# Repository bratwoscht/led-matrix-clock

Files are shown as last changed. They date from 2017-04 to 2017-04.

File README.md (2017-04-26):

# led-matrix-clock
LED matrix clock with telegram bot

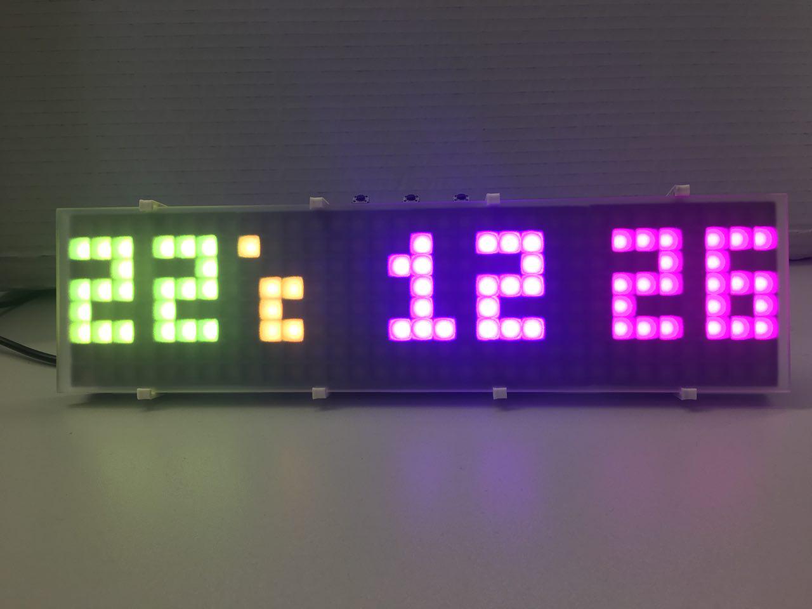
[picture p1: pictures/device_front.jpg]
device front

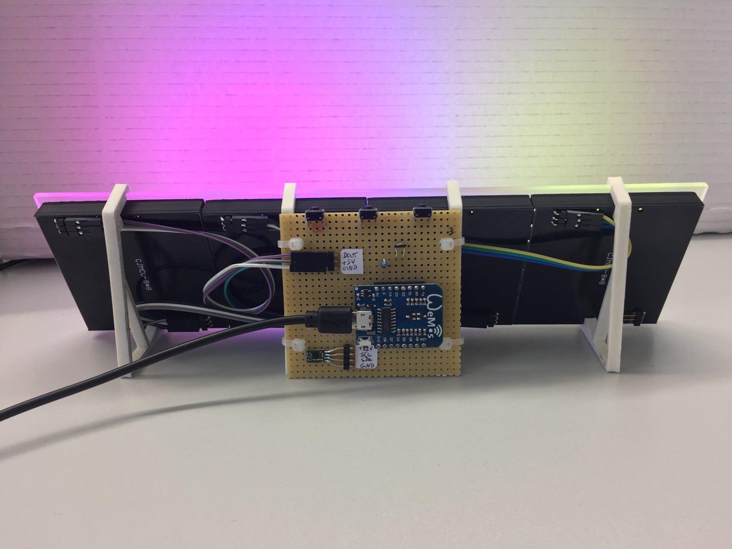
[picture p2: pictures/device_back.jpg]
device back


# Hardware

## Bill of materials

| Menge | Preis  | Beschreibung | Link |
| ----- | --- | --- | ----- |
| 1 | 0,22€  | 2.54mm THT Angled Pin Header| https://www.reichelt.de/index.html?ARTIKEL=SL%201X40W%202,54 |
| 4 | 10,66€ | 8x8 RGB LED Matrix with WS2812 LEDs (I soldered the angled pin headers). ATTENTION: On this module DIN and DOUT are interchanged. | https://www.banggood.com/de/CJMCU-64-Bit-WS2812-5050-RGB-LED-Driver-Development-Board-p-981678.html |
| 1 | 0,75€  | Prototyping board (approx. 70x70 mm) |  https://www.reichelt.de/index.html?ARTIKEL=HPR%20100X100 |
| 3 | 0,15€  | Push button. | https://www.reichelt.de/index.html?ARTIKEL=TASTER%203305 |
| 1 | 4,41€  | ESP8266 WLAN module | https://www.banggood.com/de/WeMos-D1-Mini-V2-NodeMcu-4M-Bytes-Lua-WIFI-Internet-Of-Things-Development-Board-Based-ESP8266-p-1115398.html |
| 1 | 1,15€  | LM75 I2C temperature sensor (I used a custom PCB from a former project) | http://www.ebay.de/itm/New-LM75A-Temperatur-Sensor-High-speed-I2C-Interface-Development-Board-Modul-/272434029114 |
| 1 | | LDR (unknown type with approx. 5-10kR at 10Lux) | | 
| 1 | 0,10€  | Resistor 1kR for the voltage divider at the LDR | https://www.reichelt.de/index.html?ARTICLE=1315 |

## Schematics

The prototyping pcb look like this:
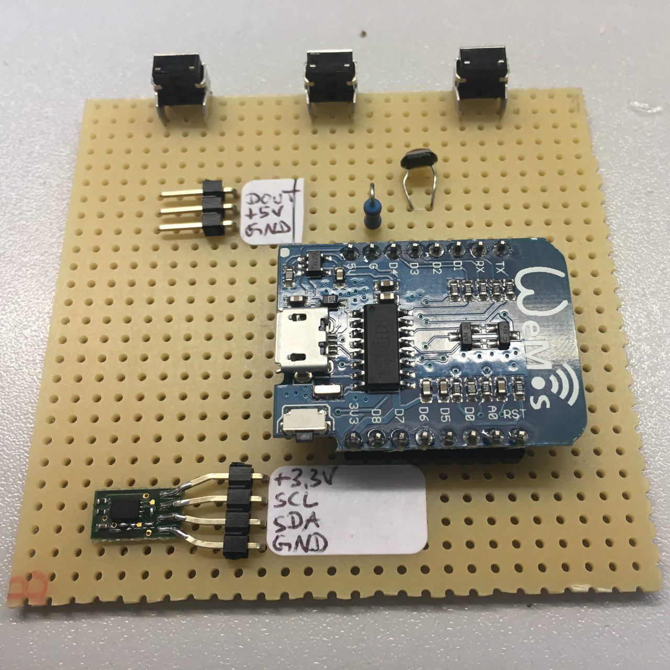
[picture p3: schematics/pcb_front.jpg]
pcb front PCB front

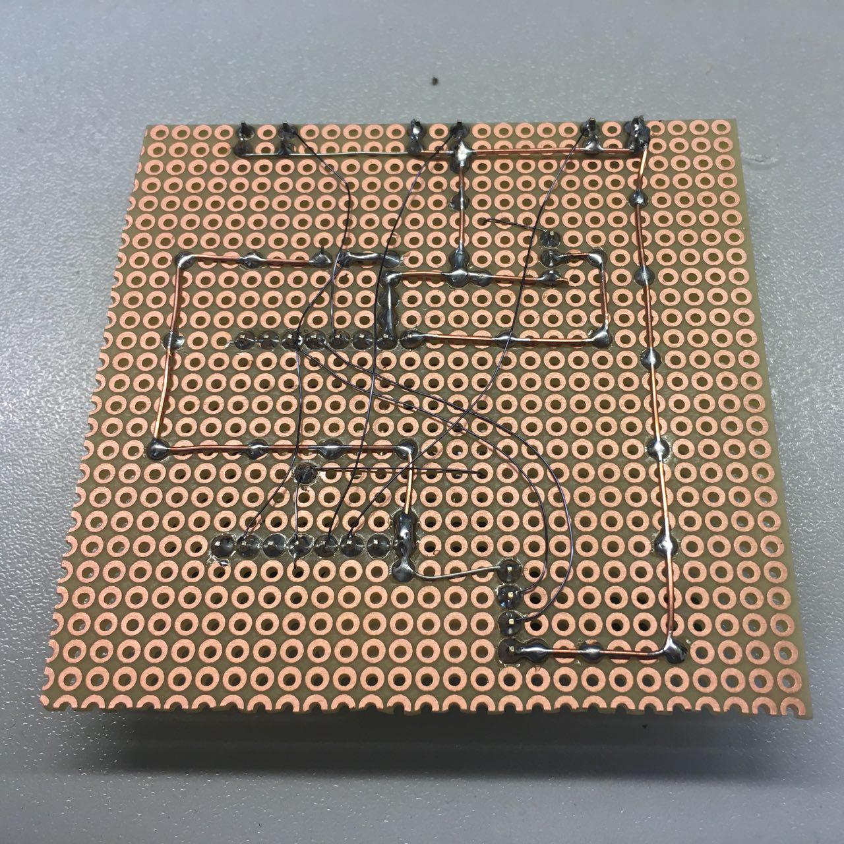
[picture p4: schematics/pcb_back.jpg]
pcb back PCB back


### LDR
```
       +3.3V
      |
     .-.
 --> | |
 --> | | LDR
     '-'
      |
      +--- A0
      |
     .-.
     | |
     | | 1kR
     '-'
      |
       GND
```

### Push buttons
```
   T           T           T
  ---         ---         ---
+-o o-+     +-o o-+     +-o o-+
|     |     |     |     |     |
|G    |     |G    |     |G    |
|N    |D    |N    |D    |N    |D
|D    |7    |D    |6    |D    |3
```

### Connector for the LED matrix
```
DOUT  --  D5
+5V
GND
```

### Connector for the LM75
```
SCL  --  D1
SDA  --  D2
```

# Casing

The device is put together using four 8x8 RGB LED matrix modules: 
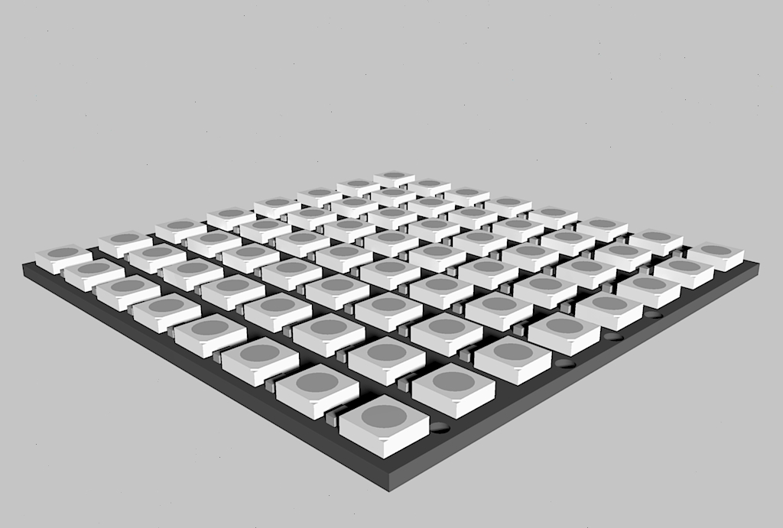
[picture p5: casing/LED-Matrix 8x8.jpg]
LED matrix 8x8 The LED-matrix 8x8


The matrix is held by a frame:
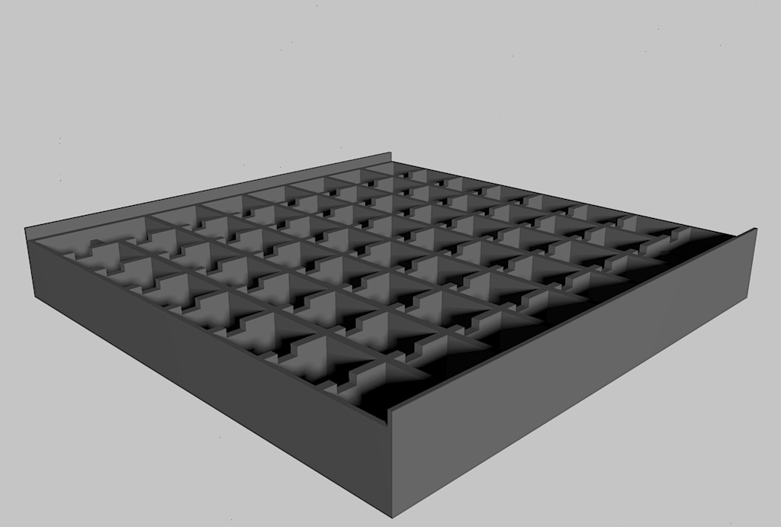
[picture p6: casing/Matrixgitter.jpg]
matrix frame The matrix frame


In front of the frame I put acrylic glass pane with 271 x 71 x 3 mm
The whole device is held together by four of these clips:
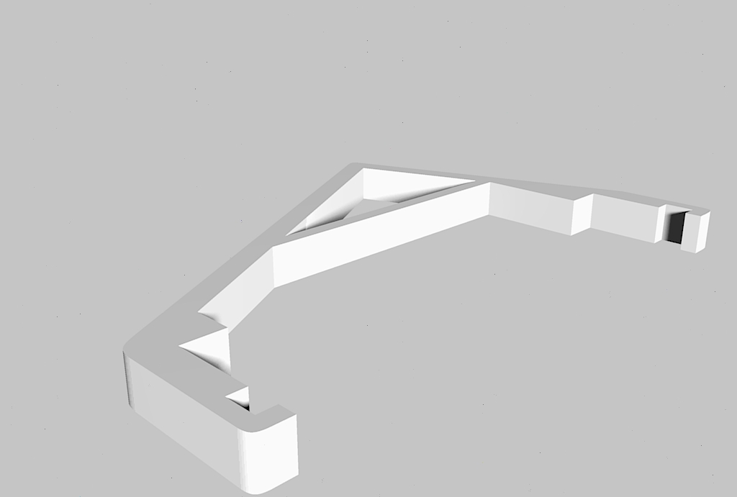
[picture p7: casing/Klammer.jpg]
clip The clip


Voila! The whole device:
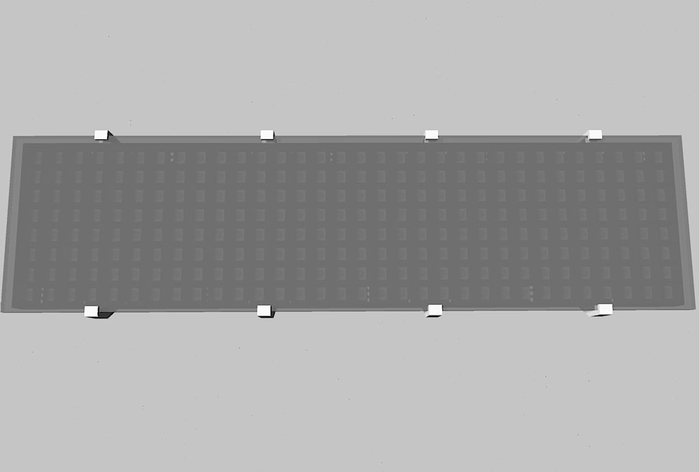
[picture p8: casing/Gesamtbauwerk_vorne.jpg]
front view The whole device front view


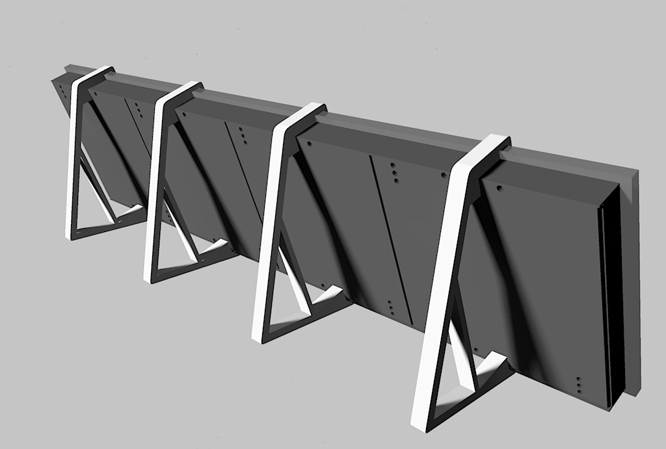
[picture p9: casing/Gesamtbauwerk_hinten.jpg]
back view The whole device back view


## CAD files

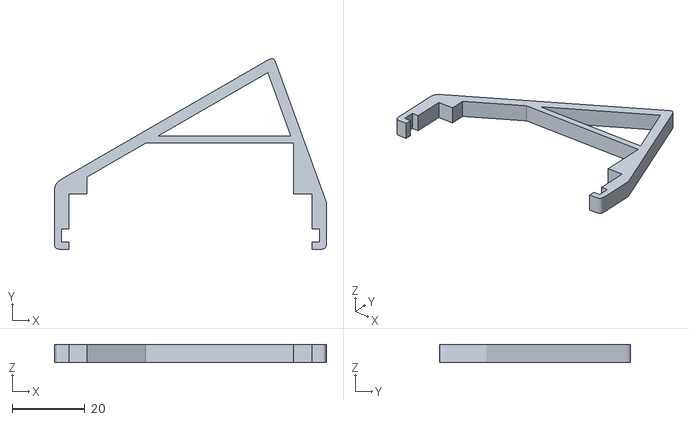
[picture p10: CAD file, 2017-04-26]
casing/Klammer.stl
74.8 x 52.5 x 5.00

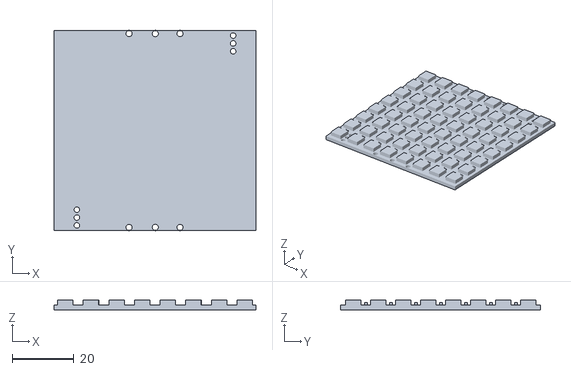
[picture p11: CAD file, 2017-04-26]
casing/LED-Matrix 8x8.stl
65.4 x 64.9 x 3.20

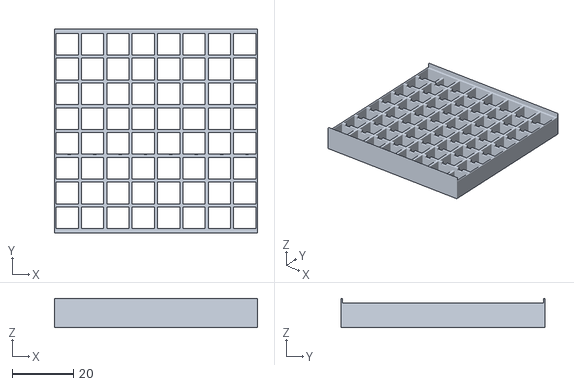
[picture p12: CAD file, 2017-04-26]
casing/Matrixgitter.stl
66.4 x 66.8 x 9.60

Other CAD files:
casing/Gesamtbauwerk.skp
casing/Klammer.skp
casing/LED-Matrix 8x8.skp
casing/Matrixgitter.skp

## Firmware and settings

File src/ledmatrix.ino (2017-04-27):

#include <ESP8266WiFi.h>          //https://github.com/esp8266/Arduino
#include <DNSServer.h>
#include <ESP8266WebServer.h>
#include "WiFiManager.h"          //https://github.com/tzapu/WiFiManager
#include <WiFiClientSecure.h>
#include <ESP8266mDNS.h>
#include <Ticker.h> //for LED status
#include <Adafruit_GFX.h>
#include <Adafruit_NeoMatrix.h>
#include <Adafruit_NeoPixel.h>
#include <Wire.h>
#include <EEPROM.h>
#include "LM75.h"
#include "fonts/pixel5pt7b.h"
#include "fonts/pixel3x5.h"
#include "NTPClient_ch.h"
#include "TelegramBot.h"


/* Todo:
 *  Farbsets definieren
 *  Farbwahl auf HSB
 *  
 *  SSID lokal konfigurieren
 *  OTA Update
 *   
*/
WiFiUDP ntpUDP;


int show = 1;

int16_t sensor_temperature=0;

// You can specify the time server pool and the offset (in seconds, can be
// changed later with setTimeOffset() ). Additionaly you can specify the
// update interval (in milliseconds, can be changed using setUpdateInterval() ).
NTPClient timeClient(ntpUDP, "europe.pool.ntp.org", 3600, 3600000); // update 1x pro Stunde
//NTPClient timeClient(ntpUDP, "europe.pool.ntp.org", 3600, 5000);

Ticker ticker;
ESP8266WebServer server ( 80 );
LM75 sensor;
#define PIN D5 // was: 4, was: 6

// Taster: D3 (GPIO0), D6 (GPIO12), D7 (GPIO13), LDR=A0

#define KEY1 D3
#define KEY2 D6
#define KEY3 D7

// Color definitions
#define BLACK    0x0000
#define BLUE     0x001F
#define RED      0xF800
#define GREEN    0x07E0
#define CYAN     0x07FF
#define MAGENTA  0xF81F
#define YELLOW   0xFFE0
#define WHITE    0xFFFF

#define MAXCLOCKFACE 7
#define MAXSELECTEDCOLOR 11 // max color number+1

#define round(x) ((x)>=0?(long)((x)+0.5):(long)((x)-0.5))

Adafruit_NeoMatrix matrix = Adafruit_NeoMatrix(32, 8, PIN,
                            NEO_MATRIX_TOP     + NEO_MATRIX_RIGHT +
                            NEO_MATRIX_COLUMNS + NEO_MATRIX_PROGRESSIVE,
                            NEO_GRB            + NEO_KHZ800);

const uint16_t colors[] = {
  matrix.Color(255, 0, 0), matrix.Color(0, 255, 0), matrix.Color(0, 0, 255)
};

TelegramBOT bot("");
#define SCROLL_RESET 16380
String scrollmessage;
int16_t _scrmsgcnt = SCROLL_RESET;
uint8_t _repeatmessage = 0;

uint16_t color1;
uint16_t color2;
uint16_t color3;
uint16_t color4;
uint16_t color5;
uint16_t color6;

#define STARTMARKER 0x98765432
#define ENDMARKER   0xd570015

union _EEP {
  struct __attribute__((packed)) {
    uint32_t startmarker; // magic number
    uint8_t minBrightness;
    uint8_t maxBrightness;
    uint8_t clockface;
    int8_t  temperatureOffset;
    uint16_t p1i;
    uint16_t p2i;
    uint16_t p3i;
    uint16_t p4i;
    uint16_t p5i;
    uint16_t p6i;
    uint8_t  selectedcolor;
    char     BotToken[60];  // normal size: 45 characters
    uint32_t endmarker; // magic number
  } data;
  byte buf[0];
} eep;

void initEEPROM() {
  eep.data.startmarker = STARTMARKER;
  eep.data.endmarker = ENDMARKER;
  eep.data.minBrightness = 1;
  eep.data.maxBrightness = 250;
  eep.data.clockface = 7;
  eep.data.temperatureOffset = -40; // -52 = 5,2 Grad abziehen
  eep.data.p1i = matrix.Color(255, 0, 255);
  eep.data.p2i = matrix.Color(255, 0, 150);
  eep.data.p3i = matrix.Color(255, 0, 50);
  eep.data.p4i = matrix.Color(255, 255, 0);
  eep.data.p5i = matrix.Color(255, 150, 0);
  eep.data.p6i = matrix.Color(0, 255, 0);
  eep.data.BotToken[0] = 0;
  eep.data.selectedcolor = 0;
}

void loadEEPROM(void) {
  uint16_t i;
  uint16_t seep = sizeof(eep);
  
  for(i=0; i<seep; i++) {
    eep.buf[i] = EEPROM.read(i); 
  }
}

void saveEEPROM(void) {
  uint16_t i;
  uint16_t seep = sizeof(eep);
  
  for(i=0; i<seep; i++) {
    EEPROM.write(i, eep.buf[i]); 
  }
  EEPROM.commit();
}

String convertUnicodeToASCII(String unicodeStr){
  String out = "";
  uint16_t len = unicodeStr.length();
  char iChar;
  for (uint16_t i = 0; i < len; i++){
     iChar = unicodeStr[i];
     if(iChar == '\\'){ // got escape char
       iChar = unicodeStr[++i];
       if(iChar == 'u'){ // got unicode hex
         char unicode[7];
         unicode[0] = '0';
         unicode[1] = 'x';
         unicode[6] = '\0';
         for (uint8_t j = 0; j < 4; j++){
           iChar = unicodeStr[++i];
           unicode[j + 2] = iChar;
         }
         uint16_t unicodeVal = strtol(unicode, 0, 16); //convert the string
         uint8_t conv = unicodeVal;
         switch (unicodeVal) {
           case 196: conv = 142; break;  //Ä
           case 214: conv = 153; break;  //Ö
           case 220: conv = 154; break;  //Ü
           case 223: conv = 224; break;  //ß
           case 228: conv = 132; break;  //ä
           case 246: conv = 148; break;  //ö
           case 252: conv = 129; break;  //ü
         }
         
         out += (char)conv;
       } else if(iChar == '/'){
         out += iChar;
       } else if(iChar == 'n'){
         out += '\n';
       }
     } else {
       out += iChar;
     }
  }
  return out;
}

/********************************************
   EchoMessages - function to Echo messages
 ********************************************/
void Bot_ExecMessages() {
  for (int i = 1; i < bot.message[0][0].toInt() + 1; i++)      {
    Serial.print("Bot-Nachricht ");
    Serial.println(i);
    Serial.println(bot.message[i][5]);
    //    bot.message[i][5]=bot.message[i][5].substring(1,bot.message[i][5].length());
    String cmd = bot.message[i][5].substring(0, 2);
    if (cmd == "/f") {
      String val = bot.message[i][5].substring(3, bot.message[i][5].length());
      bot.sendMessage(bot.message[i][4], "Clockface " + val, "");
      eep.data.clockface = val.toInt();
      saveEEPROM();
    }
    if (cmd == "/v") {
      String val = bot.message[i][5].substring(3, bot.message[i][5].length());
      bot.sendMessage(bot.message[i][4], "Colorset " + val, "");
      eep.data.selectedcolor = val.toInt();
      if (eep.data.selectedcolor >= MAXSELECTEDCOLOR)
        eep.data.selectedcolor = 0;
      selectColor();
      saveEEPROM();
    }
    if (cmd == "/b") {
      String val = bot.message[i][5].substring(3, bot.message[i][5].length());
      bot.sendMessage(bot.message[i][4], "Brightness " + val, "");
      int16_t tmp = val.toInt();
      if (tmp < 1) tmp = 1;
      if (tmp > 255) tmp = 255;
      eep.data.maxBrightness = tmp;
      saveEEPROM();
    }
    if (cmd == "/t") {
      String val = bot.message[i][5].substring(3, bot.message[i][5].length());
      val.replace(",",".");
      float tmp = val.toFloat();
      int16_t itmp = round(tmp*10);
      int16_t tmpoffset = itmp - sensor_temperature;
      if (tmpoffset < -150) tmpoffset = -150;
      if (tmpoffset > 150) tmpoffset = 150;
      Serial.println("Temperature offset is now " + String(tmpoffset));
//      bot.sendMessage(bot.message[i][4], "Temperature offset is now " + String(tmpoffset), "");
      bot.sendMessage(bot.message[i][4], "Set current temperature to " + val + ", offset=" + tmpoffset + " [1/10deg]", "");
      eep.data.temperatureOffset = tmpoffset;
      saveEEPROM();
    }    
    if (cmd == "/c") {
      String space = bot.message[i][5].substring(2, 3);
      String colNo,rgb,val;
      if (space != " ") {
        colNo = bot.message[i][5].substring(2, 3);
        rgb = bot.message[i][5].substring(3, 4);
        val = bot.message[i][5].substring(4, bot.message[i][5].length());
      } else {
        colNo = bot.message[i][5].substring(3, 4);
        rgb = bot.message[i][5].substring(4, 5);
        val = bot.message[i][5].substring(5, bot.message[i][5].length());
      }
      uint16_t col;
      switch (colNo.toInt()) {
        case 1: col = eep.data.p1i; break;
        case 2: col = eep.data.p2i; break;
        case 3: col = eep.data.p3i; break;
        case 4: col = eep.data.p4i; break;
        case 5: col = eep.data.p5i; break;
        case 6: col = eep.data.p6i; break;
      }
      uint16_t col_r = (col & 0xf800) >> 8;
      uint16_t col_g = (col & 0x7e0) >> 3;
      uint16_t col_b = (col & 0x1f) << 3;
      if (rgb == "r")
        col_r = val.toInt();
      if (rgb == "g")
        col_g = val.toInt();
      if (rgb == "b")
        col_b = val.toInt();
      col = matrix.Color(col_r, col_g, col_b);
      
      bot.sendMessage(bot.message[i][4], "set color " + colNo + " type "+rgb+" to "+val+", color is R="+String(col_r)+", G="+String(col_g)+", B="+String(col_b), "");

      switch (colNo.toInt()) {
        case 1: eep.data.p1i = col; break;
        case 2: eep.data.p2i = col; break;
        case 3: eep.data.p3i = col; break;
        case 4: eep.data.p4i = col; break;
        case 5: eep.data.p5i = col; break;
        case 6: eep.data.p6i = col; break;
      }
      eep.data.selectedcolor = 0;
      selectColor();
      saveEEPROM();
    }
    if (cmd == "/m") {
      String msg = bot.message[i][5].substring(3, bot.message[i][5].length());
      if (msg == "") {
        _repeatmessage = 0;
        show = 1;
        bot.sendMessage(bot.message[i][4], F("Message deleted"), "");
      } else {
//        Serial.println("Nachricht: "+msg);
        scrollmessage = convertUnicodeToASCII(msg);
        _repeatmessage = 1;
//        Serial.println("nach Uni.: "+scrollmessage);
        bot.sendMessage(bot.message[i][4], "Message: " + msg, "");
        _scrmsgcnt=SCROLL_RESET;
        show = 2;
      }
    }
    if ( (cmd == "/s") || (cmd == "/h") ) {
      bot.sendMessage(bot.message[i][4], F("Welcome to LED Matrix Clock"), "");
      bot.sendMessage(bot.message[i][4], F("/m msg: send message msg"), "");
      bot.sendMessage(bot.message[i][4], F("/m : /m without any text deletes current message"), "");
      bot.sendMessage(bot.message[i][4], F("/b x: set max brightness to x [1..255]"), "");
      bot.sendMessage(bot.message[i][4], F("/t x: calibrate temperature to current temperature x"), "");
      bot.sendMessage(bot.message[i][4], F("/i : MORE INFO"), "");
    }
    if (cmd == "/i") {
      bot.sendMessage(bot.message[i][4], "/f x: switch to clockface x [1.."+String(MAXCLOCKFACE)+"]", "");
      bot.sendMessage(bot.message[i][4], "/v x: switch to color set x [0.."+String(MAXSELECTEDCOLOR-1)+"],", "");
      bot.sendMessage(bot.message[i][4], F("0 is the individual set which can be changed using /c"), "");
      bot.sendMessage(bot.message[i][4], F("/c : change color. 6 colors [1..6] can be changed, each has"), "");
      bot.sendMessage(bot.message[i][4], F("red (r), green (r) and blue (r) components. To change color 1 red"), "");
      bot.sendMessage(bot.message[i][4], F("to value 200, type: /c 1r200. Value range [0..255]"), "");
    }
  }
  bot.message[0][0] = "";   // All messages have been replied - reset new messages
}

void tick()
{
  //toggle state
  int state = digitalRead(BUILTIN_LED);  // get the current state of GPIO1 pin
  digitalWrite(BUILTIN_LED, !state);     // set pin to the opposite state
}

//gets called when WiFiManager enters configuration mode
void configModeCallback (WiFiManager *myWiFiManager) {
  Serial.println("Entered config mode");
  Serial.println(WiFi.softAPIP());
  //if you used auto generated SSID, print it
  Serial.println(myWiFiManager->getConfigPortalSSID());
  //entered config mode, make led toggle faster
  ticker.attach(0.2, tick);
  matrix.fillScreen(0);
  matrix.setCursor(0, 0);
  matrix.setTextColor(RED);
  matrix.setFont(0);
  matrix.print("WLAN");
  matrix.show();
}

void handleTelegram() {
  String page = FPSTR(HTTP_HEAD);
  page.replace("{v}", "LED Matrix Clock");
  page += FPSTR(HTTP_SCRIPT);
  page += FPSTR(HTTP_STYLE);
  page += FPSTR(HTTP_HEAD_END);
  page += "<h1>";
  page += "LED Matrix Clock";
  page += "</h1>";
  page += F("<h3>Telegram Bot</h3>");
  
  for ( uint8_t i = 0; i < server.args(); i++ ) {
    if (server.argName(i)[0] == 't') {
      strncpy(eep.data.BotToken, server.arg(i).c_str(), 59);
      page += "Bot token saved!<br/><br/>";
      saveEEPROM();
      bot.setToken(eep.data.BotToken);
    }
  }

  page += "<br/>Enter Telegram Bot token here. Leave blank to disable Bot.<br/>If you need help on how to create a Bot token: <a href='https://ds-tools.net/ledmatrix' target='_blank'>click here</a>.<br/>";

  page += "<br/><form method='post' action='telegram'><input id='t' name='t' maxlength=58 placeholder='Telegram Bot token' value='"+String(eep.data.BotToken)+"'><br/>";
  page += "<br/><button type='submit'>save</button></form><br/><hr>";

  page += "<br/><form action=\"/\" method=\"get\"><button>Go back</button></form><br/>";

  page += FPSTR(HTTP_END);

  server.send(200, "text/html", page);
}

void handleOptions() {
  String p1r = String(((eep.data.p1i & 0xf800) >> 8));
  String p1g = String(((eep.data.p1i & 0x7e0) >> 3));
  String p1b = String(((eep.data.p1i & 0x1f) << 3));
  String p2r = String(((eep.data.p2i & 0xf800) >> 8));
  String p2g = String(((eep.data.p2i & 0x7e0) >> 3));
  String p2b = String(((eep.data.p2i & 0x1f) << 3));
  String p3r = String(((eep.data.p3i & 0xf800) >> 8));
  String p3g = String(((eep.data.p3i & 0x7e0) >> 3));
  String p3b = String(((eep.data.p3i & 0x1f) << 3));
  String p4r = String(((eep.data.p4i & 0xf800) >> 8));
  String p4g = String(((eep.data.p4i & 0x7e0) >> 3));
  String p4b = String(((eep.data.p4i & 0x1f) << 3));
  String p5r = String(((eep.data.p5i & 0xf800) >> 8));
  String p5g = String(((eep.data.p5i & 0x7e0) >> 3));
  String p5b = String(((eep.data.p5i & 0x1f) << 3));
  String p6r = String(((eep.data.p6i & 0xf800) >> 8));
  String p6g = String(((eep.data.p6i & 0x7e0) >> 3));
  String p6b = String(((eep.data.p6i & 0x1f) << 3));
  String wf = String(eep.data.clockface); // clockface
  delay(0);
/*
      switch (colNo.toInt()) {
        case 1: col = eep.data.p1i; break;
        case 2: col = eep.data.p2i; break;
        case 3: col = eep.data.p3i; break;
        case 4: col = eep.data.p4i; break;
        case 5: col = eep.data.p5i; break;
        case 6: col = eep.data.p6i; break;
      }
      uint16_t col_r = ((col & 0xf800) >> 8);
      uint16_t col_g = ((col & 0x7e0) >> 3);
      uint16_t col_b = ((col & 0x1f) << 3);
      if (rgb == "r")
        col_r = val.toInt();
      if (rgb == "g")
        col_g = val.toInt();
      if (rgb == "b")
        col_b = val.toInt();

*/

  for ( uint8_t i = 0; i < server.args(); i++ ) {
    delay(0);
    if (server.argName(i)[0] == 'w')
      wf = server.arg(i);
    if (server.argName(i)[0] == 'p') {
      if (server.argName(i)[1] == '1') {
        if (server.argName(i)[2] == 'r')
          p1r = server.arg(i);
        if (server.argName(i)[2] == 'g')
          p1g = server.arg(i);
        if (server.argName(i)[2] == 'b')
          p1b = server.arg(i);
      }
      if (server.argName(i)[1] == '2') {
        if (server.argName(i)[2] == 'r')
          p2r = server.arg(i);
        if (server.argName(i)[2] == 'g')
          p2g = server.arg(i);
        if (server.argName(i)[2] == 'b')
          p2b = server.arg(i);
      }
      if (server.argName(i)[1] == '3') {
        if (server.argName(i)[2] == 'r')
          p3r = server.arg(i);
        if (server.argName(i)[2] == 'g')
          p3g = server.arg(i);
        if (server.argName(i)[2] == 'b')
          p3b = server.arg(i);
      }
      if (server.argName(i)[1] == '4') {
        if (server.argName(i)[2] == 'r')
          p4r = server.arg(i);
        if (server.argName(i)[2] == 'g')
          p4g = server.arg(i);
        if (server.argName(i)[2] == 'b')
          p4b = server.arg(i);
      }
      if (server.argName(i)[1] == '5') {
        if (server.argName(i)[2] == 'r')
          p5r = server.arg(i);
        if (server.argName(i)[2] == 'g')
          p5g = server.arg(i);
        if (server.argName(i)[2] == 'b')
          p5b = server.arg(i);
      }
      if (server.argName(i)[1] == '6') {
        if (server.argName(i)[2] == 'r')
          p6r = server.arg(i);
        if (server.argName(i)[2] == 'g')
          p6g = server.arg(i);
        if (server.argName(i)[2] == 'b')
          p6b = server.arg(i);
      }
    }
  }

  color1 = ((p1r.toInt() >> 3) << 11) | ((p1g.toInt() >> 2) << 5) | (p1b.toInt() >> 3);
  color2 = ((p2r.toInt() >> 3) << 11) | ((p2g.toInt() >> 2) << 5) | (p2b.toInt() >> 3);
  color3 = ((p3r.toInt() >> 3) << 11) | ((p3g.toInt() >> 2) << 5) | (p3b.toInt() >> 3);
  eep.data.clockface = wf.toInt();
  delay(0);
  saveEEPROM();
  delay(0);
  /*
    Serial.print("p1:");
    Serial.printlncolor1);
    Serial.print("p1r-Int:");
    Serial.println(p1r.toInt());
    Serial.print("p1r:");
    Serial.println(p1r);

    Serial.print("p2:");
    Serial.printlncolor2);
    Serial.print("p3:");
    Serial.printlncolor3);
  */
  /*  matrix.drawPixel(0,0,p1i);
    matrix.drawPixel(1,0,p2i);
    matrix.drawPixel(0,1,p3i);
    matrix.show();
  */

  String page = FPSTR(HTTP_HEAD);
  page.replace("{v}", "LED Matrix Clock - colors");
  page += FPSTR(HTTP_SCRIPT);
  page += FPSTR(HTTP_STYLE);
  page += FPSTR(HTTP_HEAD_END);
  page += F("<h1>");
  page += F("LED Matrix Clock - colors");
  page += F("</h1>");
  page += F("<h3>LEDs</h3>");
  page += F("Diese seite sorgt derzeit fuer Probleme, die Uhr stuerzt oefter ab.");
  delay(0);

  page += F("<br/><form method='post' action='options'>");
  page += F("Clockface: <input id='wf' name='wf' length=1 value='");
  page += wf;
  page += F("'><br/>");
  page += F("<hr>");
  page += F("Farbe 1 rot: <input id='p1r' name='p1r' length=3 value='");
  page += p1r;
  page += F("'><br/>");
  page += F("Farbe 1 gr&uuml;n: <input id='p1g' name='p1g' length=3 value='");
  page += p1g;
  page += F("'><br/>");
  page += F("Farbe 1 blau: <input id='p1b' name='p1b' length=3 value='");
  page += p1b;
  page += F("'><br/>");
  page += F("<hr>");
  page += F("Farbe 2 rot: <input id='p2r' name='p2r' length=3 value='");
  page += p2r;
  page += F("'><br/>");
  page += F("Farbe 2 gr&uuml;n: <input id='p2g' name='p2g' length=3 value='");
  page += p2g;
  page += F("'><br/>");
  page += F("Farbe 2 blau: <input id='p2b' name='p2b' length=3 value='");
  page += p2b;
  page += F("'><br/>");
  delay(0);
  page += F("<hr>");
  page += F("Farbe 3 rot: <input id='p3r' name='p3r' length=3 value='");
  page += p3r;
  page += F("'><br/>");
  page += F("Farbe 3 gr&uuml;n: <input id='p3g' name='p3g' length=3 value='");
  page += p3g;
  page += F("'><br/>");
  page += F("Farbe 3 blau: <input id='p3b' name='p3b' length=3 value='");
  page += p3b;
  page += F("'><br/>");
  page += F("<hr>");
  page += F("Farbe 4 rot: <input id='p4r' name='p4r' length=3 value='");
  page += p4r;
  page += F("'><br/>");
  page += F("Farbe 4 gr&uuml;n: <input id='p4g' name='p4g' length=3 value='");
  page += p4g;
  page += F("'><br/>");
  page += F("Farbe 4 blau: <input id='p4b' name='p4b' length=3 value='");
  page += p4b;
  page += F("'><br/>");
  delay(0);
  page += F("<hr>");
  page += F("Farbe 5 rot: <input id='p5r' name='p5r' length=3 value='");
  page += p5r;
  page += F("'><br/>");
  page += F("Farbe 5 gr&uuml;n: <input id='p5g' name='p5g' length=3 value='");
  page += p5g;
  page += F("'><br/>");
  page += F("Farbe 5 blau: <input id='p5b' name='p5b' length=3 value='");
  page += p5b;
  page += F("'><br/>");
  page += F("<hr>");
  page += F("Farbe 6 rot: <input id='p6r' name='p6r' length=3 value='");
  page += p6r;
  page += F("'><br/>");
  page += F("Farbe 6 gr&uuml;n: <input id='p6g' name='p6g' length=3 value='");
  page += p6g;
  page += F("'><br/>");
  page += F("Farbe 6 blau: <input id='p6b' name='p6b' length=3 value='");
  page += p6b;
  page += F("'><br/>");
  delay(0);
  page += F("<hr>");
  page += F("<br/><button type='submit'>setzen</button></form><br/>");

  delay(0);
  page += FPSTR(HTTP_END);

  server.send(200, "text/html", page);
  delay(0);
}

void handleRoot() {
  String page = FPSTR(HTTP_HEAD);
  page.replace("{v}", "LED Matrix Clock Configuration");
  page += FPSTR(HTTP_SCRIPT);
  page += FPSTR(HTTP_STYLE);
  page += FPSTR(HTTP_HEAD_END);
  page += "<h1>";
  page += "LED Matrix Clock Configuration";
  page += "</h1>";
  page += F("<h3>Configuration</h3>");
  page += "<form action=\"/telegram\" method=\"get\"><button>Telegram Bot configuration</button></form><br/>\
           <form action=\"/options\" method=\"get\"><button>Display options</button></form><br/>";
  page += FPSTR(HTTP_END);

  server.send(200, "text/html", page);
}

void handleNotFound() {
  String message = "File Not Found\n\n";
  message += "URI: ";
  message += server.uri();
  message += "\nMethod: ";
  message += ( server.method() == HTTP_GET ) ? "GET" : "POST";
  message += "\nArguments: ";
  message += server.args();
  message += "\n";

  for ( uint8_t i = 0; i < server.args(); i++ ) {
    message += " " + server.argName ( i ) + ": " + server.arg ( i ) + "\n";
  }

  server.send ( 404, "text/plain", message );
}

#define MAXTEMPHIST 16
int16_t _tempHistory[MAXTEMPHIST] = {0}; /* history of the last values used for averaging */
int16_t _tempHP = 0; /* actual write position in history buffer */

#define MAXLDRHIST 16
uint8_t _ldrHistory[MAXLDRHIST] = {0}; /* history of the last values used for averaging */
uint8_t _ldrHP = 0; /* actual write position in history buffer */
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
void loop() {
  static uint8_t cnt = 0;
  cnt++;
  if (cnt == 10) {
    cnt = 0;
    server.handleClient();
  }

  switch (show) {
    case 1: // clock
      do_clock();
      break;
    case 2: // scrollmessage
      do_scrollmessage();
      break;
  }

  doButtons();
  doLDR();
  doTemperature();
  checkRepeat();

  bot.getUpdates(bot.message[0][1]);   // launch API GetUpdates up to xxx message
  Bot_ExecMessages();

  
  delay(10);
}

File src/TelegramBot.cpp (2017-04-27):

/*
  Copyright (c) 2015 Giancarlo Bacchio. All right reserved.
  https://github.com/Gianbacchio/ESP8266-TelegramBot

  TelegramBot - Library to create your own Telegram Bot using 
  ESP8266 on Arduino IDE.
  Ref. Library at https:github/esp8266/Arduino
  
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
  You should have received a copy of the GNU Lesser General Public
  License along with this library; if not, write to the Free Software
  Foundation, Inc., 51 Franklin St, Fifth Floor, Boston, MA 02110-1301 USA
  */


#include "TelegramBot.h"


TelegramBOT::TelegramBOT(String token)	{
	_token=token;
  _stateGU = 0;
  _stateCONN = 0;
  message[0][0]="0";   // number of received messages
  message[1][0]="";    
  message[0][1]="0";  // code of last read Message
}


void TelegramBOT::setToken(String token)  {
  _token=token;
  _stateGU = 0;
  _stateCONN = 0;
  message[0][0]="0";   // number of received messages
  message[1][0]="";    
  message[0][1]="0";  // code of last read Message
}


  
/**************************************************************************************************
 * function to achieve connection to api.telegram.org and send command to telegram                *
 * (Argument to pass: URL to address to Telegram)                                                 *
 **************************************************************************************************/
byte TelegramBOT::connectToTelegram(unsigned long timeout)  {
  bool avail;
  byte ret = 0;
  //Serial.print("connectToTelegram ");Serial.println(_stateCONN);
  switch (_stateCONN) {
    case 0: {
      _mess = "";
      // Connect with api.telegram.org       
      if (client.connect("api.telegram.org", 443)) {  
        //Serial.println("GET: "+_command);
        client.println("GET /"+_command);
        _now=millis();
        _stateCONN++;
      }
    } break;
    case 1: {
      if ( (millis()-_now) > timeout ) {
        ret = 1;
        _stateCONN = 0;
        client.stop();
        Serial.println("Bot Client Timeout");
      } else {
        if (client.available())
          _stateCONN++;
      }
    } break;
    case 2: {
      uint16_t rcvcnt=0;
      while (client.available()) {
        char c = client.read();
        //Serial.print("Received: ");Serial.println(c);
        if (rcvcnt<700)  {
          _mess=_mess+c;
          rcvcnt++;
        }
      }
      ret = 1;
      _stateCONN = 0;
    } break;
  }
  return ret;
}


/***************************************************************
 * GetUpdates - function to receive all messages from telegram *
 * (Argument to pass: the last+1 message to read)             *
 ***************************************************************/
void TelegramBOT::getUpdates(String offset)  {
  if (_token == "")
    return;
//  Serial.print("Millis:");
//  Serial.println(millis());
  switch (_stateGU) {
    case 0: {
//      Serial.println("GET Update Messages ");
      _command="bot"+_token+"/getUpdates?offset="+offset+"&timeout=30";
      _stateGU++;
    } break;
    case 1: {
      byte finished = connectToTelegram(32000);
      if (finished) {
        Serial.println("Message received:");
        Serial.println(_mess);
        if (_mess == "") {
          _stateGU = 0;
        } else {
          _stateGU++;
        }
      }
    } break;
    case 2: {
      // parsing of reply from Telegram into separate received messages
      int i=0;                //messages received counter
      if (_mess!="") {
        Serial.print("Sent Update request messages up to : ");
        Serial.println(offset);
        String a="";
        int ch_count=0;
        String c;
        for (int n=1; n<_mess.length()+1; n++) {   //Search for each message start
          ch_count ++;
          c =  _mess.substring(n-1,n);
          //Serial.print(c);
          a=a+c;
          if (ch_count>8) {
            if (a.substring(ch_count-9)=="update_id")  {
              if (i>1) break;
              message[i][0]=a.substring(0, ch_count-11);
              a=a.substring(ch_count-11);
              i ++;
              ch_count=11;
            }
          }
        }
        if (i==1)  {
          message[i][0]=a.substring(0, ch_count);   //Assign of parsed message into message matrix if only 1 message)
        }
        if (i>1)  i=i-1;
      }
      //check result of parsing process
      if (_mess=="") {     
        Serial.println("failed to update");
      } else {
        if (i==0) {
          Serial.println("no new messages");
          Serial.println();
          message[0][0]="0";
        } else {
          message[0][0]=String(i);   //returns how many messages are in the array
          //Serial.println();         
          for (int b=1; b<i+1; b++)  {
            Serial.println(message[b][0]);
          }
          Serial.println();
          analyzeMessages();
        }
      }
      _stateGU = 0;
    } break;
  } // case
} 



String convAndURLEncode(String unicodeStr){
  String out = "";
  uint16_t len = unicodeStr.length();
  char iChar;
  for (uint16_t i = 0; i < len; i++){
     iChar = unicodeStr[i];
     if(iChar == '\\'){ // got escape char
       iChar = unicodeStr[++i];
       if(iChar == 'u'){ // got unicode hex
         char unicode[7];
         unicode[0] = '0';
         unicode[1] = 'x';
         unicode[6] = '\0';
         for (uint8_t j = 0; j < 4; j++){
           iChar = unicodeStr[++i];
           unicode[j + 2] = iChar;
         }
         uint16_t unicodeVal = strtol(unicode, 0, 16); //convert the string
         uint8_t conv = unicodeVal;
         switch (unicodeVal) {
           case 196: out += "Ae"; break;  //Ä
           case 214: out += "Oe"; break;  //Ö
           case 220: out += "Ue"; break;  //Ü
           case 223: out += "ss"; break;  //ß
           case 228: out += "ae"; break;  //ä
           case 246: out += "oe"; break;  //ö
           case 252: out += "ue"; break;  //ü
           default:
              out+='-';
         }
         
       } else if(iChar == '/'){
         out += iChar;
       } else if(iChar == 'n'){
         out += '\n';
       }
     } else {
       switch (iChar) {
         case ' ':
           out += "%20";
           break;
         case '&':
           out += " und ";
           break;
         default:
           out += iChar;
       }
     }
  }
  return out;
}
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

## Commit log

2017-04-26 Added casing 3D-Files
    [Gesamtbauwerk.skp, Klammer.skp, Klammer.stl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]
2017-04-26 Updated readme.md with BOM and Schematics
2017-04-26 Updated README.md with pictures of the complete device
2017-04-27 Fixed bugs and added config options for temperature and brightness
    [ledmatrix.ino]
